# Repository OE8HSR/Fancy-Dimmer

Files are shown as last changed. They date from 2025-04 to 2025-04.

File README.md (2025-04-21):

# Fancy-Dimmer
The Fancy-Dimmer is "designed" to dim LED Flatpanels.\
(Flatpanels are used to make CallibrationFrames in Astrophotography)\
**Input:** 12Vdc (10V-14,4V)\
**Output:** 12V PWM\
**PWM-Frequency:** 30kHz (Programable)\
**Imax:** 5A\
**PWM-Resolution:** 668 Counts\
Potentiometer controlled\
2 x "programable" Presets\
Programable via UPDI\
\

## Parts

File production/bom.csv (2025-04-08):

Designator | Footprint | Quantity | Value | LCSC Part #
BT1 | TerminalBlock_MaiXu_MX126-5.0-02P_1x02_P5.00mm | 1 | Battery
C1, C2 | 0805 | 2 | 10µF
C3 | 0603 | 1 | 100nF
D1, D3 | 0805 | 2 | LED
D2 | 0603 | 1 | D
J1 | TerminalBlock_MaiXu_MX126-5.0-02P_1x02_P5.00mm | 1 | Screw_Terminal_01x02
J2 | PinHeader_1x03_P2.54mm_Vertical | 1 | Conn_01x03_Pin
Q1 | TO-263-3_TabPin2 | 1 | IRLZ44N
R1 | 0805 | 1 | 560
R2 | 0805 | 1 | 0
R3 | 0805 | 1 | 100
R4, R5, R6, R7 | 0805 | 4 | 10k
R8 | 0805 | 1 | 2k2
RV1 | TerminalBlock_MaiXu_MX126-5.0-03P_1x03_P5.00mm | 1 | R_Potentiometer
SW1, SW2, SW3 | SW_SPST_B3SL-1002P | 3 | SW_Push
U1 | TO-263-3_TabPin4 | 1 | LM2937xMP
U2 | SOIC-8_3.9x4.9mm_P1.27mm | 1 | ATtiny402-SS

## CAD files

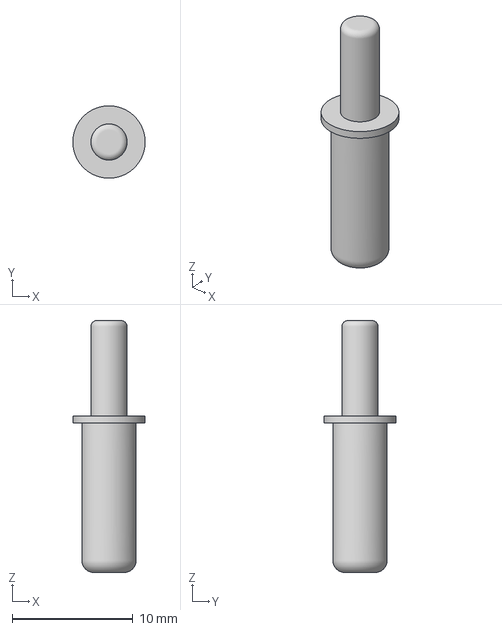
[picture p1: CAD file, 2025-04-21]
FancyDimmerHousing/knob3.3mf
6.00 x 6.00 x 20.9 mm

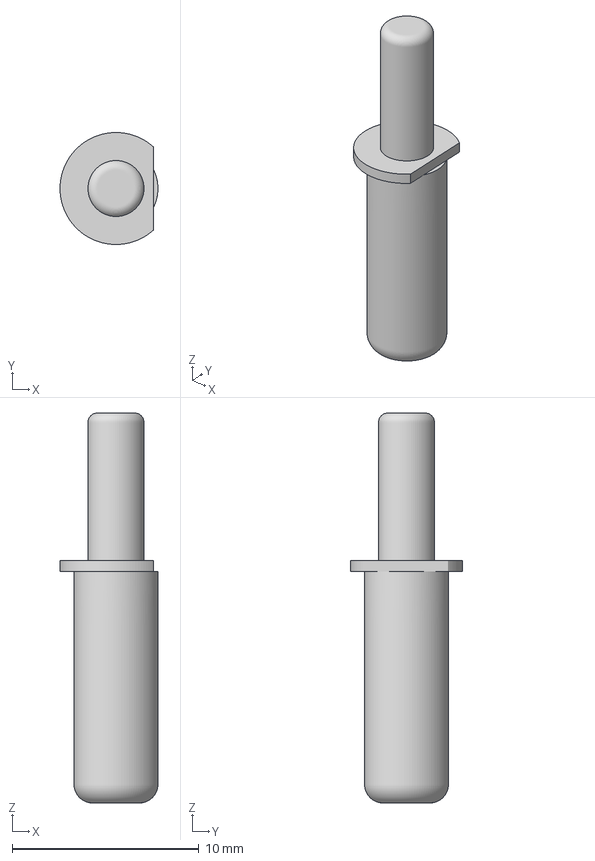
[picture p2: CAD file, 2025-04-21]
FancyDimmerHousing/knob2.3mf
5.25 x 6.00 x 20.9 mm

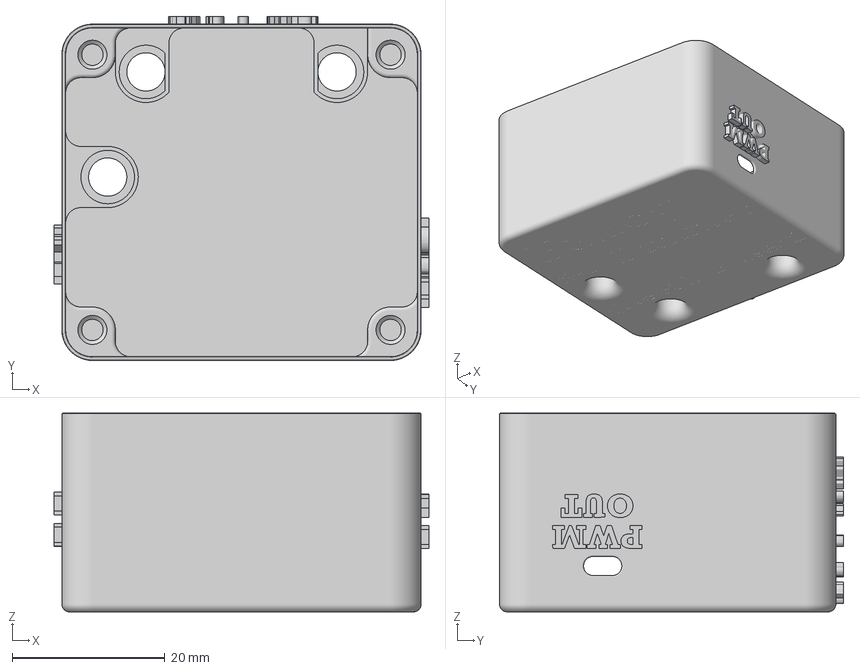
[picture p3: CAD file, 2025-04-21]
FancyDimmerHousing/FancydimmerHousing.3mf
49.0 x 45.0 x 26.0 mm

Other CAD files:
FancyDimmerHousing/knob1.3mf

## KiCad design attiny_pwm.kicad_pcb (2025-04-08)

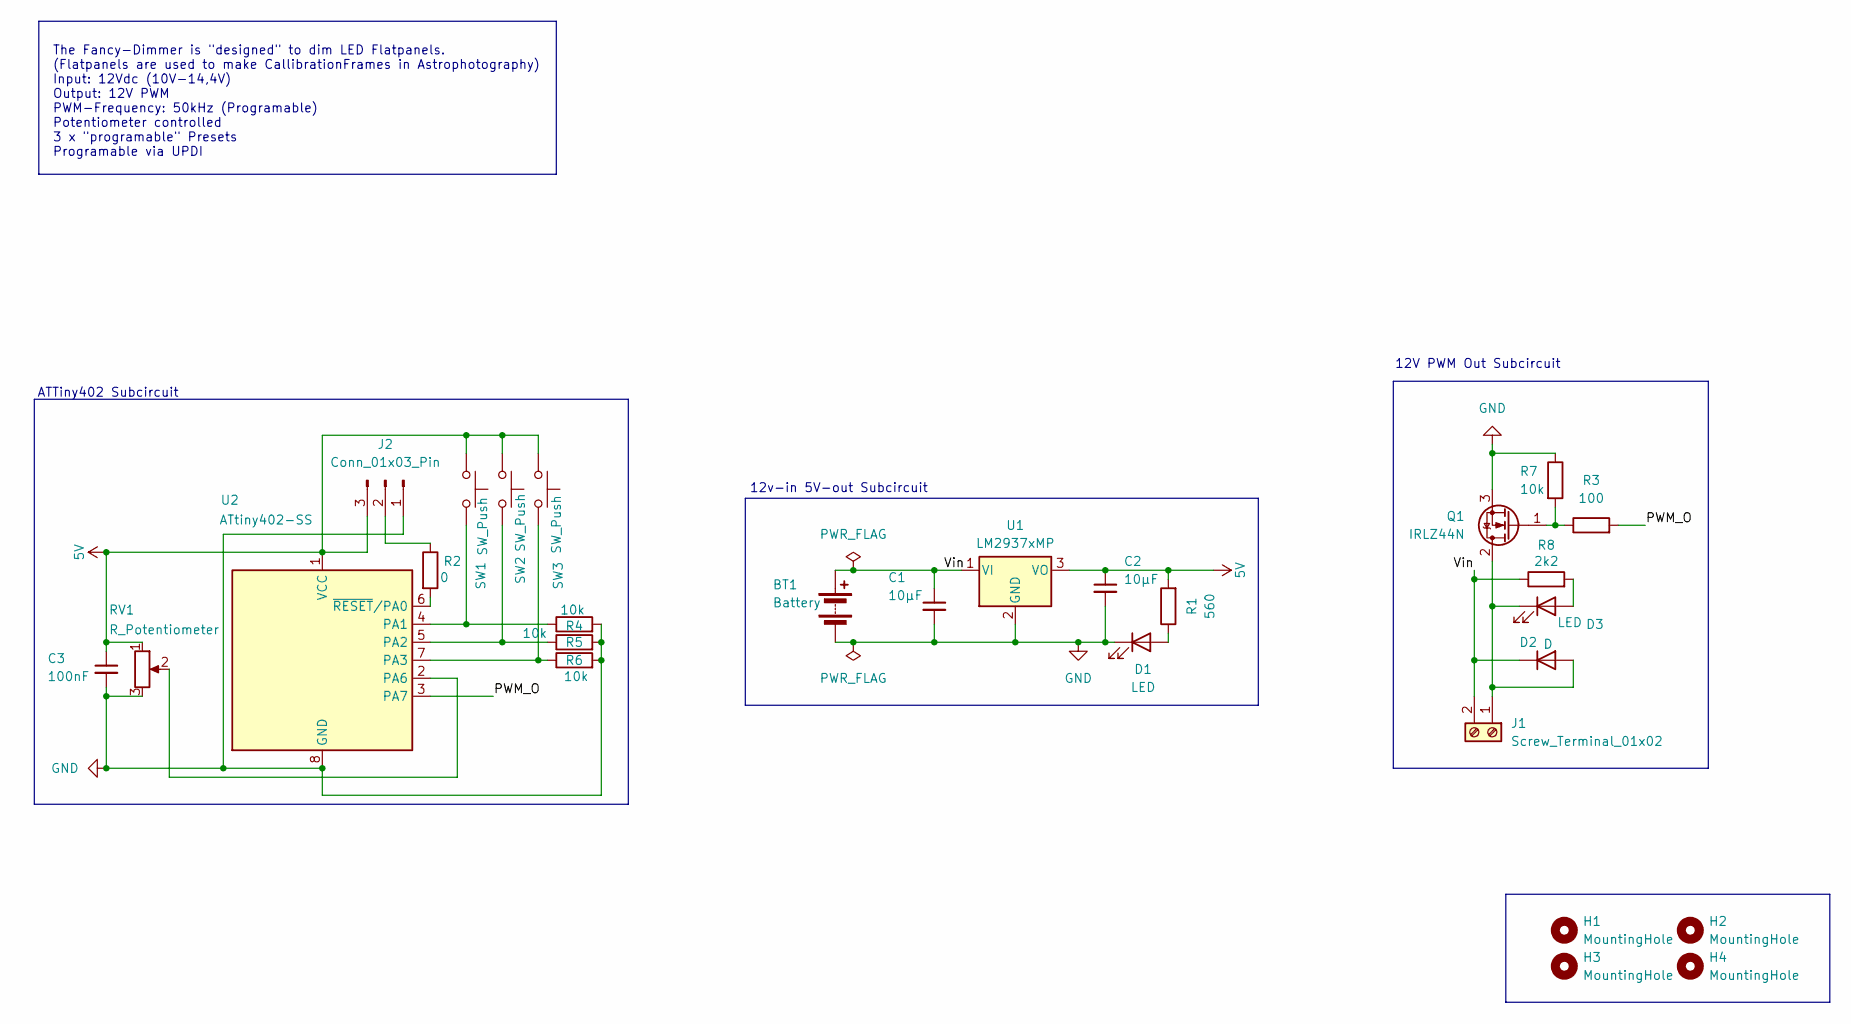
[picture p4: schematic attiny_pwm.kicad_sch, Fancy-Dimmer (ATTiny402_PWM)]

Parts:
BT1: Battery; TerminalBlock_MaiXu_MX126-5.0-02P_1x02_P5.00mm
C1, C2: 10µF; C_0805_2012Metric; Voltage 1kV; Tolerance 100%
C3: 100nF; C_0603_1608Metric; Voltage 1kV; Tolerance 100%
D1, D3: LED; LED_0805_2012Metric
D2: D; D_0603_1608Metric
H1, H2, H3, H4: MountingHole; MountingHole_3.2mm_M3_DIN965
J1: Screw_Terminal_01x02; TerminalBlock_MaiXu_MX126-5.0-02P_1x02_P5.00mm
J2: Conn_01x03_Pin; PinHeader_1x03_P2.54mm_Vertical
Q1: IRLZ44N; TO-263-3_TabPin2
R1: 560; R_0805_2012Metric
R2: 0; R_0805_2012Metric
R3: 100; R_0805_2012Metric
R4, R5, R6, R7: 10k; R_0805_2012Metric
R8: 2k2; R_0805_2012Metric
RV1: R_Potentiometer; TerminalBlock_MaiXu_MX126-5.0-03P_1x03_P5.00mm
SW1, SW2, SW3: SW_Push; SW_SPST_B3SL-1002P
U1: LM2937xMP; TO-263-3_TabPin4
U2: ATtiny402-SS; SOIC-8_3.9x4.9mm_P1.27mm

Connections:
5V: C2.1, C3.1, J2.3, R1.2, RV1.1, SW1.1, SW2.1, SW3.1, U1.3 (VO), U2.1 (VCC)
/PWM_O: R3.2, U2.3 (PA7)
/Vin: BT1.1 (+), C1.1, D2.1 (K), J1.2, R8.1, U1.1 (VI)
GND: BT1.2 (-), C1.2, C2.2, C3.2, D1.1 (K), J2.1, Q1.3 (S), R4.2, R5.2, R6.2, R7.1, RV1.3, U1.2 (GND), U2.8 (GND)
unnamed: D1.2 (A), R1.1
unnamed: D2.2 (A), D3.1 (K), J1.1, Q1.2 (D)
unnamed: D3.2 (A), R8.2
unnamed: J2.2, R2.1
unnamed: Q1.1 (G), R3.1, R7.2
unnamed: R4.1, SW1.2, U2.4 (PA1)
unnamed: R5.1, SW2.2, U2.5 (PA2)
unnamed: R6.1, SW3.2, U2.7 (PA3)
unnamed: RV1.2, U2.2 (PA6)
unnamed: R2.2, U2.6 (~RESET/PA0)

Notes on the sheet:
12V PWM Out Subcircuit
12v-in 5V-out Subcircuit
ATTiny402 Subcircuit
The Fancy-Dimmer is "designed" to dim LED Flatpanels. (Flatpanels are used to make CallibrationFrames in Astrophotography) Input: 12Vdc (10V-14,4V) Output: 12V PWM PWM-Frequency: 50kHz (Programable) Potentiometer controlled 3 x "programable" Presets Programable via UPDI

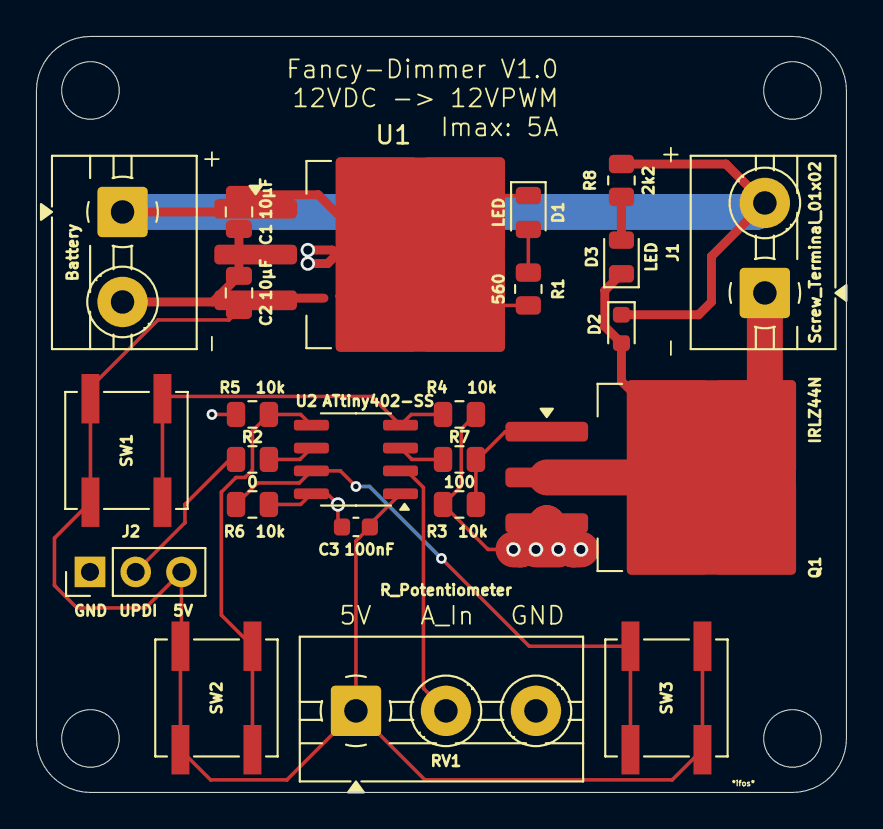
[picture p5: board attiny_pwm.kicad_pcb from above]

Board: 2 copper layers, 45.0 x 42.0 mm, 28 parts (0 on the bottom side), 14 nets.

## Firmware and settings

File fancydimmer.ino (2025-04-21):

/*
 * Firmware for FancyDimmer
 */

#include <EEPROM.h>

const uint8_t EEPROM_MARKER_B2 = 0xA5;
const uint8_t EEPROM_MARKER_B3 = 0x5A;
const uint8_t EEPROM_ADDR_B2   = 0;
const uint8_t EEPROM_ADDR_B3   = 4;



uint32_t lastButton1Time = 0;
uint8_t  button1ClickCount = 0;
bool lastB1State = false;
bool ispressed = false;
uint16_t value = 0;
uint16_t pwmWert = 0;
int pwmold = 0;
int poti = 0;
int newpwm = 0;
int oldpwm = 0;
uint16_t smoothed = 0;



const uint16_t PWM_TOP = 668;//30khz
const uint8_t button1 = PIN_PA1;
const uint8_t button2 = PIN_PA2;
const uint8_t button3 = PIN_PA3;

void blinkPWM(uint8_t times, uint16_t del) {
  for (uint8_t i = 0; i < times; i++) {
    TCA0.SINGLE.CMP0 = 0;         // LED aus
    delay(del);
    TCA0.SINGLE.CMP0 = PWM_TOP;  // LED an
    delay(del);
  }
}

void writePWMtoEEPROM(uint8_t slotAddr, uint8_t marker, uint16_t value) {
  EEPROM.update(slotAddr, marker);
  EEPROM.update(slotAddr + 1, value >> 8);
  EEPROM.update(slotAddr + 2, value & 0xFF);
}

bool readPWMfromEEPROM(uint8_t slotAddr, uint8_t marker, uint16_t &valueOut) {

    uint8_t high = EEPROM.read(slotAddr + 1);
    uint8_t low  = EEPROM.read(slotAddr + 2);
    valueOut = ((uint16_t)high << 8) | low;

}

void clearEEPROM() {
  for (uint8_t i = 0; i < 6; i++) EEPROM.update(i, 0xFF);
}



void setup() {
TCA0.SINGLE.CMP0 = 0;

  pinMode(button1, INPUT);
  pinMode(button2, INPUT);
  pinMode(button3, INPUT);

  TCA0.SPLIT.CTRLA = 0;

  PORTA.DIRSET = PIN7_bm;

  TCA0.SINGLE.CTRLA = 0;
  TCA0.SPLIT.CTRLA  = 0;
  TCA0.SPLIT.CTRLB  = 0;
  TCA0.SINGLE.CNT   = 0;
  TCA0.SPLIT.CTRLD  = 0;
  TCA0.SINGLE.CTRLB = TCA_SINGLE_WGMODE_SINGLESLOPE_gc | TCA_SINGLE_CMP0EN_bm;
  TCA0.SINGLE.PER = PWM_TOP;
  TCA0.SINGLE.CMP0 = 0;
  TCA0.SINGLE.CTRLA = TCA_SINGLE_CLKSEL_DIV1_gc | TCA_SINGLE_ENABLE_bm;
}

void loop() {


int raw = ((uint32_t)analogRead(PIN_PA6) * PWM_TOP) / 1023;
bool b1 = digitalRead(button1);
bool b2 = digitalRead(button2);
bool b3 = digitalRead(button3);

if((abs(oldpwm - raw)) > 2){
  pwmWert = PWM_TOP - raw;
  oldpwm = raw; 
}
else {
  pwmWert = PWM_TOP - oldpwm ;
}





if (b1 && !lastB1State) {
  uint32_t now = millis();
  if (now - lastButton1Time < 2000) {
    button1ClickCount++;
  } else {
    button1ClickCount = 1;
  }
  lastButton1Time = now;

  if (button1ClickCount >= 5) {
    clearEEPROM(); 
    delay(500);
    blinkPWM(5, 500); 
    button1ClickCount = 0;
  }
}
lastB1State = b1;

if(b2 && b1) {
  writePWMtoEEPROM(EEPROM_ADDR_B2, EEPROM_MARKER_B2, pwmWert);
  blinkPWM(2, 1000);
}
else if(b3 && b1) {
  writePWMtoEEPROM(EEPROM_ADDR_B3, EEPROM_MARKER_B3, pwmWert);
  blinkPWM(2, 1000);
  
}
else if(b2) {
  readPWMfromEEPROM(EEPROM_ADDR_B2, EEPROM_MARKER_B2, value);
  pwmold = pwmWert;
  ispressed = true;
  blinkPWM(3, 100);
  
}
else if(b3) {
  readPWMfromEEPROM(EEPROM_ADDR_B3, EEPROM_MARKER_B3, value);
  pwmold = pwmWert;
  ispressed = true;
  blinkPWM(3, 100);
  
}


if(ispressed) {
  TCA0.SINGLE.CMP0 = value;
  if(abs(pwmold - pwmWert) >= 3){
    ispressed = false;
    pwmold = pwmWert;
  }
  return;
}

TCA0.SINGLE.CMP0 = pwmWert;

}

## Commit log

2025-03-27 Files Uploaded
    [attiny_pwm-B_Cu.gbl, attiny_pwm-B_Mask.gbs, attiny_pwm-B_Paste.gbp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]
2025-03-27 uploaded BOM
2025-04-08 erased fuckups
    [attiny_pwm.kicad_pcb, attiny_pwm.kicad_sch]
2025-04-08 uploaded html BOM and production files
    [bom.csv, designators.csv, positions.csv]
2025-04-21 uploaded housing files and firmware
    [FancydimmerHousing.3mf, knob1.3mf, knob2.3mf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]
